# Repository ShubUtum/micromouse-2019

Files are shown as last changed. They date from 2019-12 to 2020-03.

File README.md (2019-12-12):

TODOs:

- [x] write a gitignore file
- [x] Timer Interrupt
- [x] PWM
- [x] UART TX, USB interface
- [x] Motor driver, H-Bridge interface
- [x] Motor Encoder 
- [x] PWM fix
- [x] ADC
- [ ] UART RX
- [ ] Schematic, routing
- [ ] PID controller
- [ ] moveing forward alignment & correction
- [ ] rotate left & right based on the POSCNT
- [ ] Map generation (maze discovery)
- [ ] finding shortest path to goal

- [ ] LED for measuring execution time
- [ ] UART, BT interface
- [ ] Visualization of UART data

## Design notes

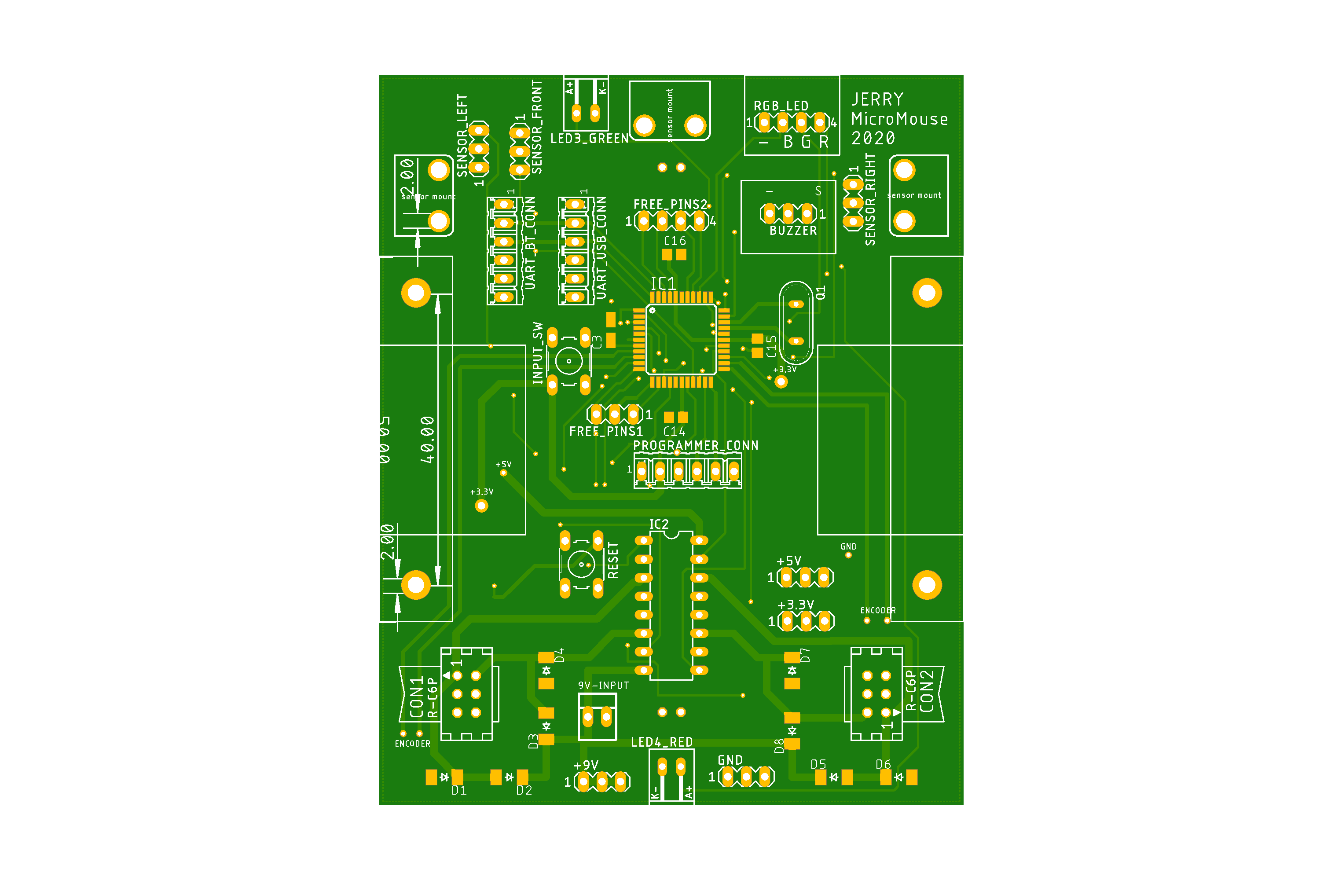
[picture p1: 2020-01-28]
Eagle/top.png

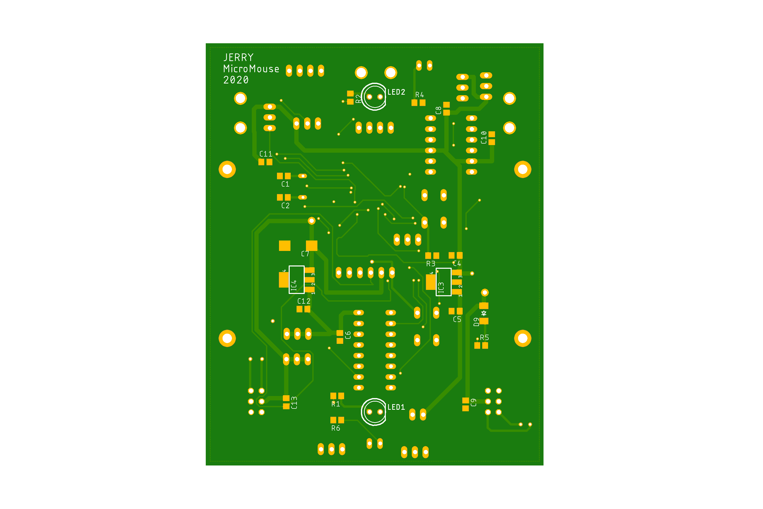
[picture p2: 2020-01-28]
Eagle/bottom.png

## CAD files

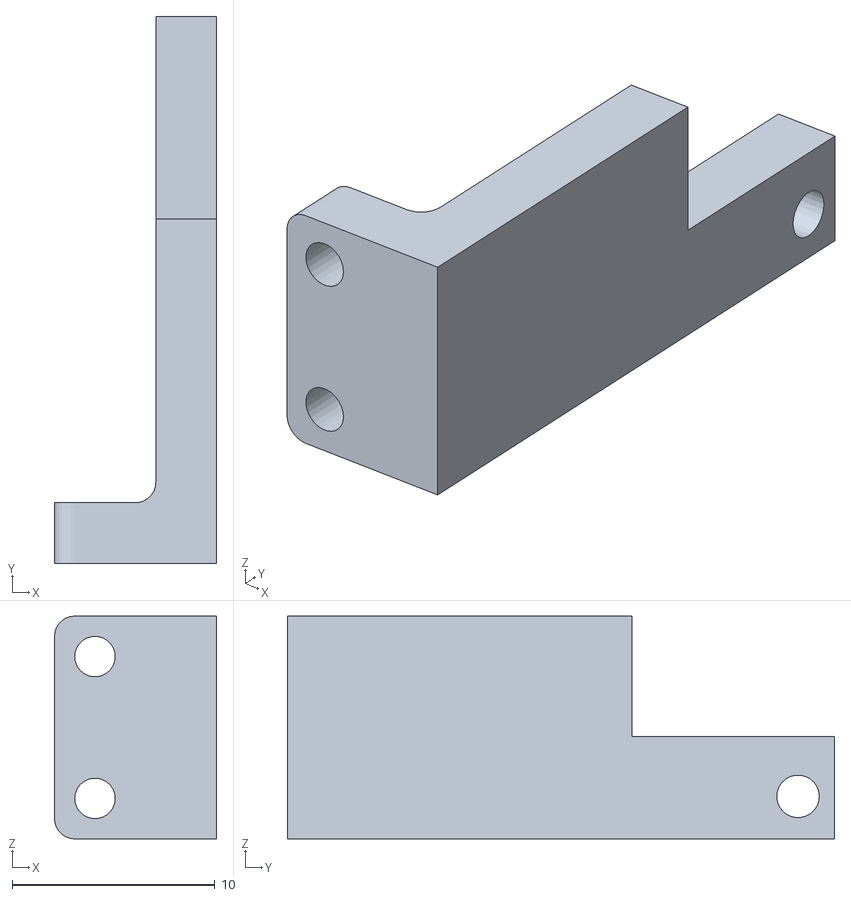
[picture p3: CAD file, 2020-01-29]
mount_models/sensormount.stl
8.00 x 27.0 x 11.0

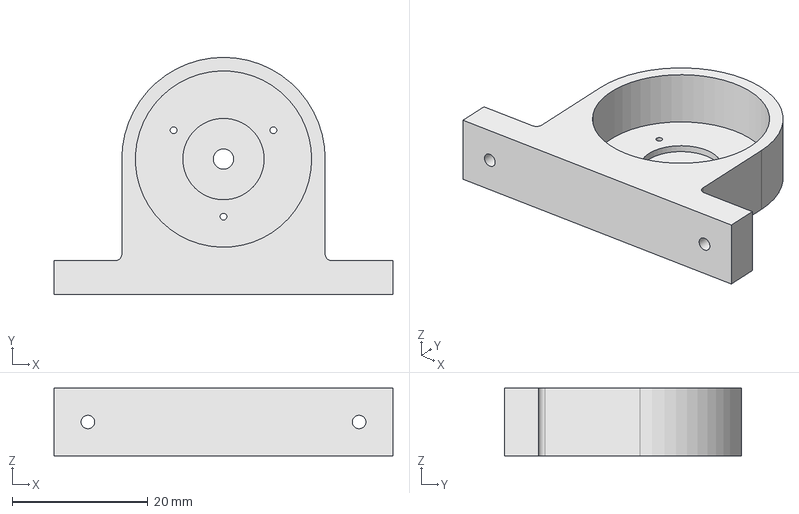
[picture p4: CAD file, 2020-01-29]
mount_models/skatch.FCStd
50.0 x 35.0 x 10.0 mm

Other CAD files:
mount_models/sensor.FCStd
mount_models/motormount.stl

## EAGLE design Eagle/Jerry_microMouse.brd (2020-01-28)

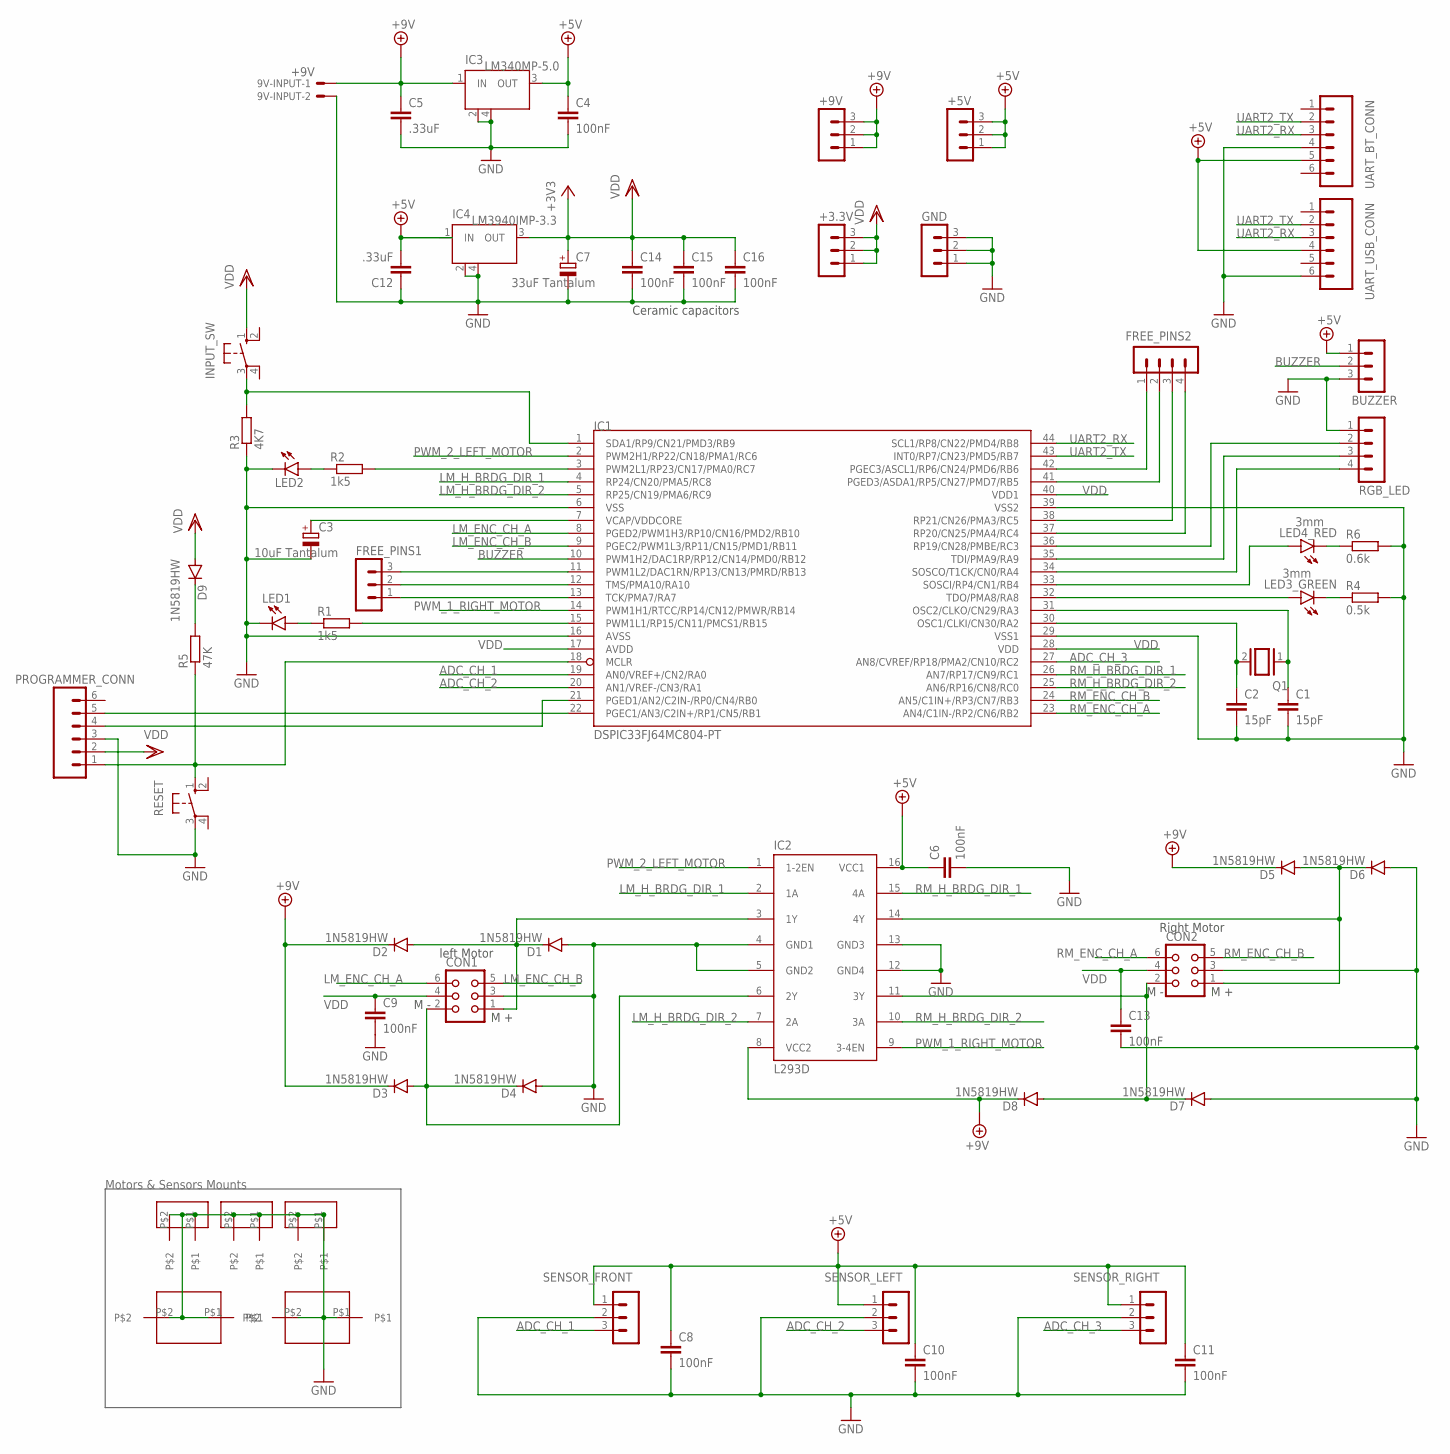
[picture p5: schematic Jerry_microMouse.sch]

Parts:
9V-INPUT: +9V; 22-23-2021
+3.3V, +5V, +9V: MA03-1
BUZZER: MA03-1
C1, C2: 15pF; C0805
C3: 10uF Tantalum; CT3216
C4, C6, C8, C9, C10, C11, C13, C14, C15, C16: 100nF; C0805
C5, C12: .33uF; C0805
C7: 33uF Tantalum; CT7343
CON1, CON2: CON06L
D1, D2, D3, D4, D5, D6, D7, D8, D9: 1N5819HW; SOD-123_MINI-SMA
FREE_PINS1: MA03-1
FREE_PINS2: MA04-1
GND: MA03-1
IC1: DSPIC33FJ64MC804-PT; TQFP44
IC2: L293D; DIL16
IC3: LM340MP-5.0; SOT223
IC4: LM3940IMP-3.3; SOT223
INPUT_SW: 10-XX; B3F-10XX
LED1, LED2: LED5MM
LED3_GREEN, LED4_RED: 3mm; Q62902-B155
PROGRAMMER_CONN: M06; 06P
Q1: XTAL/S; QS
R1, R2: 1k5; R0805
R3: 4K7; R0805
R4: 0.5k; R0805
R5: 47K; R0805
R6: 0.6k; R0805
RESET: 10-XX; B3F-10XX
RGB_LED: MA04-1
SENSOR_FRONT: MA03-1
SENSOR_LEFT: MA03-1
SENSOR_RIGHT: MA03-1
SENS_MNT_F: SENSOR_MOUNT_F; SENSOR_MOUNT
SENS_MNT_L: SENSOR_MOUNT_L; SENSOR_MOUNT
SENS_MNT_R: SENSOR_MOUNT_R; SENSOR_MOUNT
U$1, U$2: MOTOR_MOUNT
UART_BT_CONN: M06; 06P
UART_USB_CONN: M06; 06P

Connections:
+5V: +5V.1, +5V.2, +5V.3, BUZZER.1, C4.1, C6.1, C8.1, C10.1, C11.1, C12.2, IC2.16 (VCC1), IC3.3 (OUT), IC4.1 (IN), SENSOR_FRONT.1, SENSOR_LEFT.1, SENSOR_RIGHT.1, UART_BT_CONN.5, UART_USB_CONN.4
+9V: 9V-INPUT.1, +9V.1, +9V.2, +9V.3, C5.1, D2.C, D3.C, D5.C, D8.C, IC2.8 (VCC2), IC3.1 (IN)
ADC_CH_1: IC1.19 (AN0/VREF+/CN2/RA0), SENSOR_FRONT.3
ADC_CH_2: IC1.20 (AN1/VREF-/CN3/RA1), SENSOR_LEFT.3
ADC_CH_3: IC1.27 (AN8/CVREF/RP18/PMA2/CN10/RC2), SENSOR_RIGHT.3
BUZZER: BUZZER.2, IC1.10 (PWM1H2/DAC1RP/RP12/CN14/PMD0/RB12)
GND: 9V-INPUT.2, BUZZER.3, C1.2, C2.2, C3.-, C4.2, C5.2, C6.2, C7.-, C8.2, C9.2, C10.2, C11.2, C12.1, C13.2, C14.2, C15.2, C16.2, CON1.3, CON2.3, D1.A, D4.A, D6.A, D7.A, GND.1, GND.2, GND.3, IC1.6 (VSS), IC1.16 (AVSS), IC1.29 (VSS1), IC1.39 (VSS2), IC2.4 (GND1), IC2.5 (GND2), IC2.12 (GND4), IC2.13 (GND3), IC3.2 (GND), IC3.4 (GND), IC4.2 (GND), IC4.4 (GND), LED1.K (C), LED2.K (C), PROGRAMMER_CONN.3, R3.1, R4.2, R6.2, RESET.3, RGB_LED.1, SENSOR_FRONT.2, SENSOR_LEFT.2, SENSOR_RIGHT.2, SENS_MNT_F.P$1, SENS_MNT_F.P$2, SENS_MNT_L.P$1, SENS_MNT_L.P$2, SENS_MNT_R.P$1, SENS_MNT_R.P$2, U$1.P$1, U$1.P$2, U$2.P$1, U$2.P$2, UART_BT_CONN.4, UART_USB_CONN.6
LM_ENC_CH_A: CON1.6, IC1.8 (PGED2/PWM1H3/RP10/CN16/PMD2/RB10)
LM_ENC_CH_B: CON1.5, IC1.9 (PGEC2/PWM1L3/RP11/CN15/PMD1/RB11)
LM_H_BRDG_DIR_1: IC1.4 (RP24/CN20/PMA5/RC8), IC2.2 (1A)
LM_H_BRDG_DIR_2: IC1.5 (RP25/CN19/PMA6/RC9), IC2.7 (2A)
LM_M+: CON1.1, D1.C, D2.A, IC2.3 (1Y)
LM_M-: CON1.2, D3.A, D4.C, IC2.6 (2Y)
unnamed: IC1.3 (PWM2L1/RP23/CN17/PMA0/RC7), R2.2
unnamed: LED2.A, R2.1
unnamed: IC1.22 (PGEC1/AN3/C2IN+/RP1/CN5/RB1), PROGRAMMER_CONN.5
unnamed: IC1.1 (SDA1/RP9/CN21/PMD3/RB9), INPUT_SW.3, R3.2
unnamed: IC1.32 (TDO/PMA8/RA8), LED3_GREEN.A
unnamed: C2.1, IC1.30 (OSC1/CLKI/CN30/RA2), Q1.2
unnamed: C1.1, IC1.31 (OSC2/CLKO/CN29/RA3), Q1.1
unnamed: IC1.21 (PGED1/AN2/C2IN-/RP0/CN4/RB0), PROGRAMMER_CONN.4
unnamed: LED3_GREEN.K (C), R4.1
unnamed: IC1.15 (PWM1L1/RP15/CN11/PMCS1/RB15), R1.2
unnamed: IC1.33 (SOSCI/RP4/CN1/RB4), LED4_RED.A
unnamed: IC1.34 (SOSCO/T1CK/CN0/RA4), RGB_LED.4
unnamed: LED1.A, R1.1
unnamed: IC1.35 (TDI/PMA9/RA9), RGB_LED.3
unnamed: D9.C, R5.2
unnamed: IC1.36 (RP19/CN28/PMBE/RC3), RGB_LED.2
unnamed: FREE_PINS1.3, IC1.11 (PWM1L2/DAC1RN/RP13/CN13/PMRD/RB13)
unnamed: FREE_PINS2.1, IC1.42 (PGEC3/ASCL1/RP6/CN24/PMD6/RB6)
unnamed: FREE_PINS2.2, IC1.41 (PGED3/ASDA1/RP5/CN27/PMD7/RB5)
unnamed: FREE_PINS2.3, IC1.38 (RP21/CN26/PMA3/RC5)
unnamed: LED4_RED.K (C), R6.1
unnamed: FREE_PINS2.4, IC1.37 (RP20/CN25/PMA4/RC4)
unnamed: FREE_PINS1.2, IC1.12 (TMS/PMA10/RA10)
unnamed: FREE_PINS1.1, IC1.13 (TCK/PMA7/RA7)
PWM_1_RIGHT_MOTOR: IC1.14 (PWM1H1/RTCC/RP14/CN12/PMWR/RB14), IC2.9 (3-4EN)
PWM_2_LEFT_MOTOR: IC1.2 (PWM2H1/RP22/CN18/PMA1/RC6), IC2.1 (1-2EN)
RESET: IC1.18 (MCLR), PROGRAMMER_CONN.1, R5.1, RESET.1 (S)
RM_ENC_CH_A: CON2.6, IC1.23 (AN4/C1IN-/RP2/CN6/RB2)
RM_ENC_CH_B: CON2.5, IC1.24 (AN5/C1IN+/RP3/CN7/RB3)
RM_H_BRDG_DIR_1: IC1.26 (AN7/RP17/CN9/RC1), IC2.15 (4A)
RM_H_BRDG_DIR_2: IC1.25 (AN6/RP16/CN8/RC0), IC2.10 (3A)
RM_M+: CON2.1, D5.A, D6.C, IC2.14 (4Y)
RM_M-: CON2.2, D7.C, D8.A, IC2.11 (3Y)
UART2_RX: IC1.44 (SCL1/RP8/CN22/PMD4/RB8), UART_BT_CONN.3, UART_USB_CONN.3
UART2_TX: IC1.43 (INT0/RP7/CN23/PMD5/RB7), UART_BT_CONN.2, UART_USB_CONN.2
VCAP/VDDCORE: C3.+, IC1.7 (VCAP/VDDCORE)
VDD: +3.3V.1, +3.3V.2, +3.3V.3, C7.+, C9.1, C13.1, C14.1, C15.1, C16.1, CON1.4, CON2.4, D9.A, IC1.17 (AVDD), IC1.28 (VDD), IC1.40 (VDD1), IC4.3 (OUT), INPUT_SW.1 (S), PROGRAMMER_CONN.2

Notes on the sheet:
left Motor
Right Motor
M +
M -
Ceramic capacitors
Motors & Sensors Mounts

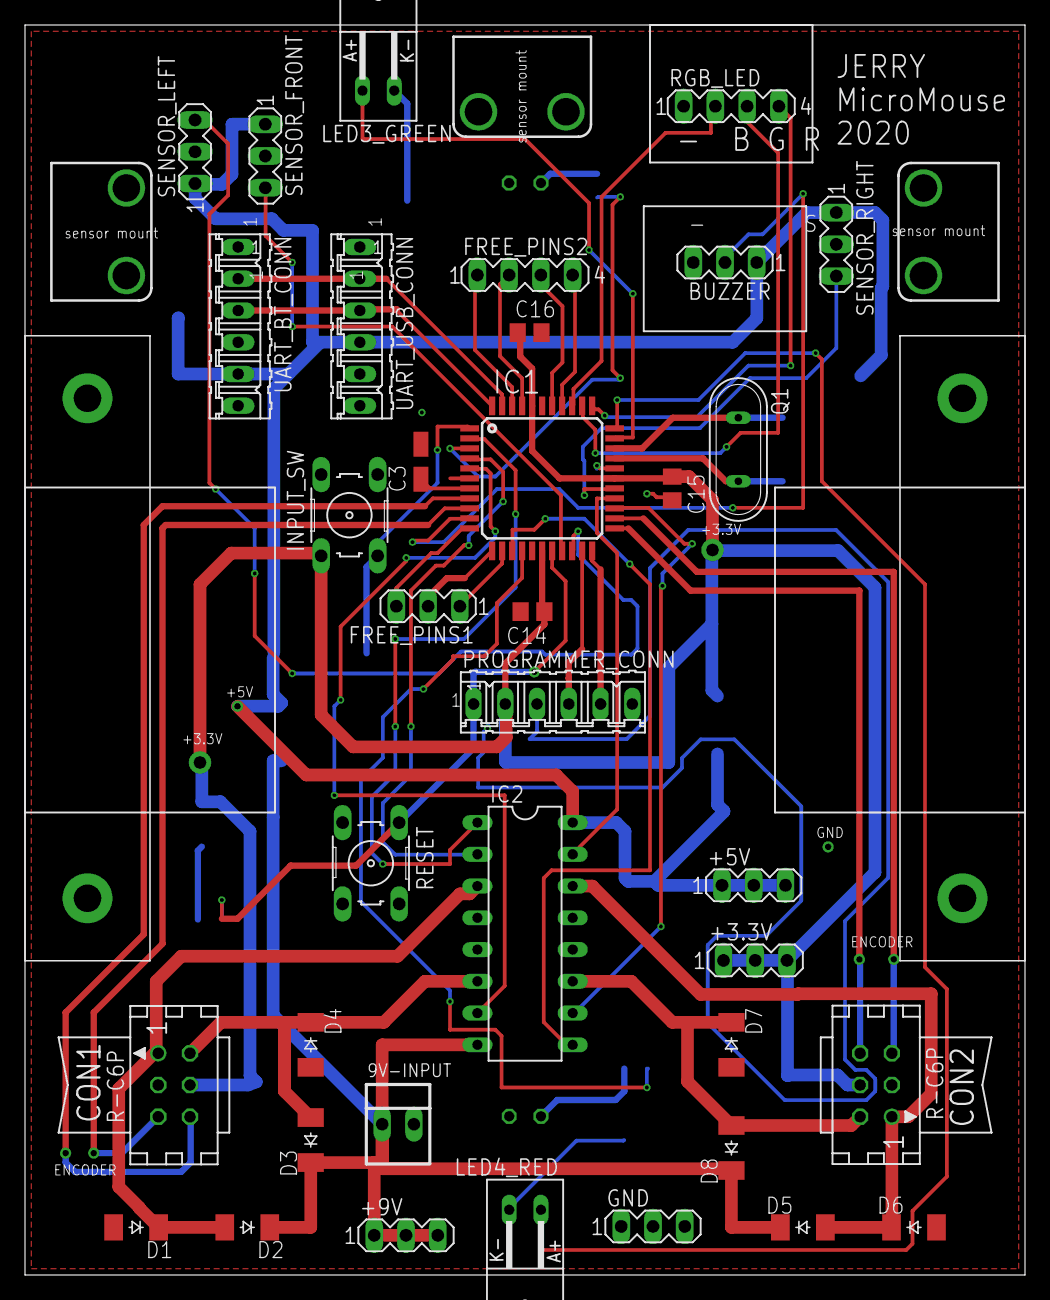
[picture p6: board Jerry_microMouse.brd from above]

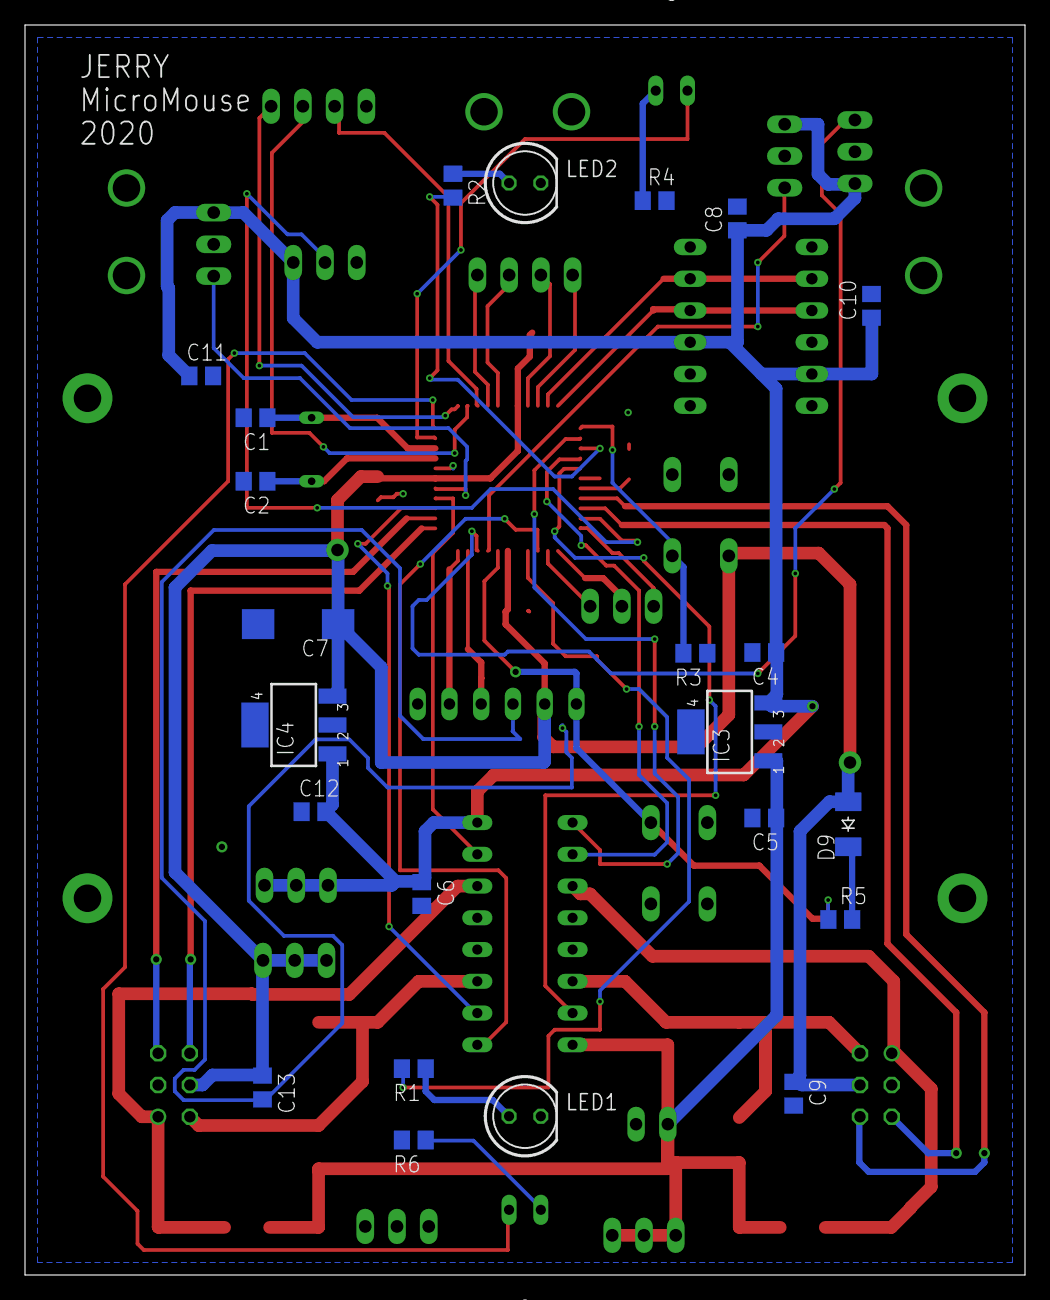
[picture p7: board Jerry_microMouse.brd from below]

Board: 2 copper layers, 80.0 x 100.0 mm, 64 parts (23 on the bottom side), 50 nets.

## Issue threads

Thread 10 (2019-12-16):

Visualization of UART data

SergeyMitchenko, 2019-12-16:
Visualize incoming UART data with a python script.
For example:
- Velocity of both motors
- Location in the maze
- Current state
- ...

(Feel free to add more)

SergeyMitchenko, 2020-01-29:
It's working right now. But it would be cool, if it would do it in real-time.

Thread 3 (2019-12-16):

Draw schematic and do the routing

SergeyMitchenko, 2019-12-16:
Draw a complete schematic and define routing of input and output pins.

Schematic has to be complete with all details.
Also, push table with all the pin mappings for quick overview over all pins.

SergeyMitchenko, 2019-12-16:
### Missing Components
- [ ] LEDs
- [ ] Decoupling Capacitors
- [ ] Power Supply (9V with two Voltage Regulators to 5V and 3V)
- [ ] Reset Button and Diode at the Programmer
- [ ] General Input Button
- [ ] Sensors
- [ ] All necessary resistors, capacitors and diods
- [ ] UART Module

### Additional ToDos
- [ ] download *.dru for Eagle from PCB Pool (Design Rules)
- [ ] add decoupling capacitors for sensors (100nF)
- [ ] add LEDs for debugging (e.g. through hole LEDs to balance the robot) (5mm low current LEDs or use a transistor SOT23)
- [ ] draw track board by hand

### Some Notes
- 10cm x 10cm PCB Board
- Resistors and capacitors of size 0805
- Supply motor with 9V and max duty cycle of 2/3 (regulate max DC according to battery voltage)
- use comments in schematic
- think about sizes and use screen layer to draw boxes
- Design connectors on circuit board so that it is easy to find correct alignment
- Use already available components (design system to use available components)

Diode:
https://de.rs-online.com/web/p/gleichrichterdioden-und-schottky-dioden/7082197/?sra=pstk

### Schematic from last semester
[micromouse1.pdf](https://github.com/ShubUtum/micromouse-2019/files/3967904/micromouse1.pdf)

SergeyMitchenko, 2020-03-07:
Done and PCB board is already ordered.

Closed 2020-03-07.

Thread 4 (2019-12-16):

Implement forward movement with alignment and correction

SergeyMitchenko, 2019-12-16:
Implement forward movement functionality, so that the robot is able to drive forward.
Sensors has to be used to measure the distance to the walls and for continuous correction of the alignment.
Cases:
- Left and right is a wall
- One wall is missing and the correction only depends on one distance
- Both walls are missing -> drive blindly forward until wall is found

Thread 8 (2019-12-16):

LED for measuring the execution time

SergeyMitchenko, 2019-12-16:
Just to measure the execution time of the program:
Toggle LED on at the start of the timer interrupt and toggle off at the end of the interrupt.

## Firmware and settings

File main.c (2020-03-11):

#include <xc.h> 
#include <stdio.h>
#include "timer.h"
#include "pwm.h"
#include "gpio.h"
#include "qei.h"
#include "uart.h"
#include "adc.h"
#include "dma.h"
#include "mouse.h"
#include "fsm.h"

#include "maze_solver.h"
// configuration bits, can be configured using GUI: window -> target memory views -> configuration bits 
/*
// FBS
#pragma config BWRP = WRPROTECT_OFF     // Boot Segment Write Protect (Boot Segment may be written)
#pragma config BSS = NO_FLASH           // Boot Segment Program Flash Code Protection (No Boot program Flash segment)

// FGS
#pragma config GWRP = OFF               // General Code Segment Write Protect (User program memory is not write-protected)
#pragma config GSS = OFF                // General Segment Code Protection (User program memory is not code-protected)

// FOSCSEL
#pragma config FNOSC = PRIPLL           // Oscillator Mode (Primary Oscillator (XT, HS, EC) w/ PLL)
#pragma config IESO = ON                // Internal External Switch Over Mode (Start-up device with FRC, then automatically switch to user-selected oscillator source when ready)

// FOSC
#pragma config POSCMD = HS              // Primary Oscillator Source (HS Oscillator Mode)
#pragma config OSCIOFNC = OFF           // OSC2 Pin Function (OSC2 pin has clock out function)
#pragma config IOL1WAY = OFF           // Peripheral Pin Select Configuration (Allow Multiple Re-configurations)
#pragma config FCKSM = CSDCMD           // Clock Switching and Monitor (Both Clock Switching and Fail-Safe Clock Monitor are disabled)

// FWDT
#pragma config WDTPOST = PS1            // Watchdog Timer Postscaler (1:1)
#pragma config WDTPRE = PR128           // WDT Prescaler (1:128)
#pragma config WINDIS = OFF             // Watchdog Timer Window (Watchdog Timer in Non-Window mode)
#pragma config FWDTEN = OFF             // Watchdog Timer Enable (Watchdog timer enabled/disabled by user software)

// FPOR
#pragma config FPWRT = PWR1             // POR Timer Value (Disabled)
#pragma config ALTI2C = OFF             // Alternate I2C  pins off
#pragma config LPOL = ON                // Motor Control PWM Low Side Polarity bit (PWM module low side output pins have active-high output polarity)
#pragma config HPOL = ON                // Motor Control PWM High Side Polarity bit (PWM module high side output pins have active-high output polarity)
#pragma config PWMPIN = ON              // Motor Control PWM Module Pin Mode bit (PWM module pins controlled by PORT register at device Reset)

// FICD
#pragma config ICS = PGD1               // Comm Channel Select (Communicate on PGC1/EMUC1 and PGD1/EMUD1)
#pragma config JTAGEN = OFF             // JTAG Port Enable (JTAG is Disabled)
*/

// DSPIC33FJ128MC804 Configuration Bit Settings
// FBS
#pragma config BWRP = WRPROTECT_OFF     // Boot Segment Write Protect (Boot Segment may be written)
#pragma config BSS = NO_FLASH           // Boot Segment Program Flash Code Protection (No Boot program Flash segment)
#pragma config RBS = NO_RAM             // Boot Segment RAM Protection (No Boot RAM)

// FSS
#pragma config SWRP = WRPROTECT_OFF     // Secure Segment Program Write Protect (Secure segment may be written)
#pragma config SSS = NO_FLASH           // Secure Segment Program Flash Code Protection (No Secure Segment)
#pragma config RSS = NO_RAM             // Secure Segment Data RAM Protection (No Secure RAM)

// FGS
#pragma config GWRP = OFF               // General Code Segment Write Protect (User program memory is not write-protected)
#pragma config GSS = OFF                // General Segment Code Protection (User program memory is not code-protected)

// FOSCSEL
#pragma config FNOSC = LPRCDIVN         // Oscillator Mode (Internal Fast RC (FRC) with divide by N)
//#pragma config FNOSC = PRIPLL           // Oscillator Mode (Primary Oscillator (XT, HS, EC) w/ PLL)
#pragma config IESO = ON                // Internal External Switch Over Mode (Start-up device with FRC, then automatically switch to user-selected oscillator source when ready)

// FOSC
#pragma config POSCMD = HS              // Primary Oscillator Source (HS Oscillator Mode)
#pragma config OSCIOFNC = OFF           // OSC2 Pin Function (OSC2 pin has clock out function)
#pragma config IOL1WAY = OFF            // Peripheral Pin Select Configuration (Allow Multiple Re-configurations)
#pragma config FCKSM = CSECME           // Clock Switching and Monitor (Both Clock Switching and Fail-Safe Clock Monitor are enabled)
//#pragma config FCKSM = CSDCMD           // Clock Switching and Monitor (Both Clock Switching and Fail-Safe Clock Monitor are disabled)

// FWDT
//#pragma config WDTPOST = PS32768        // Watchdog Timer Postscaler (1:32,768)
#pragma config WDTPOST = PS1            // Watchdog Timer Postscaler (1:1)
#pragma config WDTPRE = PR128           // WDT Prescaler (1:128)
#pragma config WINDIS = OFF             // Watchdog Timer Window (Watchdog Timer in Non-Window mode)
#pragma config FWDTEN = OFF             // Watchdog Timer Enable (Watchdog timer enabled/disabled by user software)

// FPOR
#pragma config FPWRT = PWR128           // POR Timer Value (128ms)
#pragma config ALTI2C = OFF             // Alternate I2C  pins (I2C mapped to SDA1/SCL1 pins)
#pragma config LPOL = ON                // Motor Control PWM Low Side Polarity bit (PWM module low side output pins have active-high output polarity)
#pragma config HPOL = ON                // Motor Control PWM High Side Polarity bit (PWM module high side output pins have active-high output polarity)
#pragma config PWMPIN = ON              // Motor Control PWM Module Pin Mode bit (PWM module pins controlled by PORT register at device Reset)

// FICD
#pragma config ICS = PGD1               // Comm Channel Select (Communicate on PGC1/EMUC1 and PGD1/EMUD1)
#pragma config JTAGEN = OFF             // JTAG Port Enable (JTAG is Disabled)

#define IN_SIMULATION_MODE  0

int main(void) {
    
    /*** oscillator setup --------------------------------------------------
    Here we are using PPL for 16MHz to generate 80MHz clock.
    FCY = 0.5 * (16MHz*20/(2*2)) = 40 MIPS
    ---------------------------------------------------------------------***/
    PLLFBDbits.PLLDIV  = 18; //set PPL to M=20 (18+2)
    CLKDIVbits.PLLPRE  = 0; //N1 = input/2
    CLKDIVbits.PLLPOST = 0; //N2 = output/2
    CLKDIVbits.FRCDIV  = 0;
    // Disable Watch Dog Timer
    RCONbits.SWDTEN=0;
    // Clock switch to incorporate PLL
    __builtin_write_OSCCONH( 0x03 );            // Initiate Clock Switch to Primary
    // Oscillator with PLL (NOSC=0b011)
    __builtin_write_OSCCONL( OSCCON || 0x01 );  // Start clock switching
    
    while( OSCCONbits.COSC != 0b011 );
    // In reality, give some time to the PLL to lock
    if (IN_SIMULATION_MODE != 1)
    {
       while (OSCCONbits.LOCK != 1); //Wait for PPL to lock
    }

    initIO();
    
    GREEN_LED = 1;
    RED_LED = 1;
    RGB(RED|GREEN|BLUE);
    BACK_LED = 1;
    FRONT_LED = 1;

    configUART2(57.6, 40);
    //configUART2(38.4, 40);   // BT baudrate 38400
    
    timer1_setup( 10 );        // 10 ms timer 

    LOG( "\n\r\n\r\n\r.....   START MICRO-MOUSE   ..... \n\r" );

    setupADC1();
    initDmaChannel4();

    mouse_init();
    fsm_init();

    startADC1();
    timer1_start();
    
    while(1);

    return 0;
}

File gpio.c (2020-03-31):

#include "gpio.h"
#include "uart.h"


uint16_t error_flag = 0;

#if IN_BREAD_BOARD_MODE
void initIO() {
    int i;
    /***********************************************************************
     *  PIN#     name        I/O   mappable?  function                                          Bread board change?
     ***********************************************************************
     *   17     PWM2H1(RB8)   op     N        PWM2 Left Motor Speed    (RED LED)
     *   25     PWM1H1(RB14)  op     N        PWM1 Right Motor Speed
     * 
     *   2       AN0(RA0)     ip     N        ADC ch 1
     *   3       AN1(RA1)     ip     N        ADC ch 2
     *   4       AN2(RB0)     ip     N        ADC ch 3
     * 
     *   23      RB12         op     Y        UART2 TX
     *   24      RB13         ip     Y        UART2 RX
     * 
     *   6       RB2          ip     Y        QEI1 A - Left Motor encoder ch A
     *   7       RB3          ip     Y        QEI1 B - Left Motor encoder ch B
     *   21      RB10         ip     Y        QEI2 A - Right Motor encoder ch A
     *   22      RB11         ip     Y        QEI2 B - Right Motor encoder ch B
     * 
     *   11      RB4          op     Y        GP - Left Motor H bridge dir control 1                  Yes
     *   14      RB5          op     Y        GP - Left Motor H bridge dir control 2                  Yes
     *   15      RB6          op     Y        GP - Right Motor H bridge dir control 1
     *   16      RB7          op     Y        GP - Right Motor H bridge dir control 2
     * 
     *   26      RB15         op     Y        GP - output(GREEN LED)                                  Yes
     *   12      RA4          ip     Y        Switch                                                  Yes
     * 
     *   5       AN3(RB1)                     FREE
     *   18      RB9                          FREE
     ***********************************************************************/
    // set up analog pins
    AD1CON1bits.ADON = 0; // disable ADC1 module
    AD1PCFGL=0xFFFF; //all pins are digital
   
    // set digital port direction
    // inputs
    //all pins are inputs by default
    TRISAbits.TRISA4  =1; //Switch input
    //TRISBbits.TRISB13 =1; //UART2 RX
    //TRISBbits.TRISB2  =1; //QEI1 A
    //TRISBbits.TRISB3  =1; //QEI1 B

    //outputs
    TRISBbits.TRISB8  =0; //PWM2H1 & RED LED output
    TRISBbits.TRISB15 =0; //GREEN LED output
    TRISBbits.TRISB6  =0; //RED LED
    TRISBbits.TRISB8  =0; //PWM_RED LED
    TRISBbits.TRISB4  =0; //H bridge dir control 1
    TRISBbits.TRISB5  =0; //H bridge dir control 2
    //TRISBbits.TRISB12 =0; //UART2 TX
    

    // set up remappable pins
    __builtin_write_OSCCONL(OSCCON & 0xbf); // clear bit 6 (unlock, they are usually write protected)
    // inputs
     // input pin mapping example below:, here you choose the register with the device and assign an remappable pin
    RPINR14bits.QEA1R = 2; // QEI1 A to pin RB2
    RPINR14bits.QEB1R = 3; // QEI1 B to pin RB3
    RPINR16bits.QEA2R = 10; //QEI2 A to pin RB10
    RPINR16bits.QEB2R = 11; //QEI2 B to pin RB11
    
    RPINR19bits.U2RXR = 13; // input from uart to pin RB13
    //RPINR18bits.U1RXR = 1 ; //U1RX register is pin RB1 / RP1
    
    // outputs
    //output pin mapping example below, here you choose the pin register and then map it to a device 
    //RPOR6bits.RP12R = 0b00111; // pin RB12 to SPI1 miso (the cod 0b00111 idetifies SPI miso, table in datasheet)  
    //RPOR1bits.RP2R = 0b00011; // pin RP2 is connected to UART1 TX, for coding see table 11-2 in datasheet
    //end of set up of remappable pins
    
    RPOR6bits.RP12R = 0b00101;  // Map RB12 to U2TX UART2 Transmit
    
    RPOR4bits.RP8R  = 0; //default pin output for PWM2H1 (RED LED)
    RPOR7bits.RP14R = 0; //default pin output for PWM1H1 
    
    RPOR2bits.RP4R  = 0; //default pin output for H bridge dir control 
    RPOR2bits.RP5R  = 0; //default pin output for H bridge dir control 
    RPOR3bits.RP6R  = 0; //default pin output for H bridge dir control 
    RPOR3bits.RP7R  = 0; //default pin output for H bridge dir control 
    
    RPOR7bits.RP15R = 0; //default pin output for GREEN LED //0 is default
    
    __builtin_write_OSCCONL(OSCCON | 0x40); // Lock PPS registers (lock again!)


    for (i = 0; i < 30000; i++); // short delay
}
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

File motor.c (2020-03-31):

#include <xc.h>
#include <stdio.h>
#include "gpio.h"
#include "qei.h"
#include "uart.h"
#include "pwm.h"
#include "pid.h"
#include "motor.h"


#define GET_LM_SPEED       qei1_get_poscnt()
#define GET_RM_SPEED       qei2_get_poscnt()

#define MOTOR_MAX_PWM_DC    (100*6/9) // 100% * 6v/9v

int         LM_curr_speed;  // LM moved POSCNT/10ms
int         RM_curr_speed;  // RM moved POSCNT/10ms
pid_params  LM_pid;
pid_params  RM_pid;
/************************************************************************
 ************************************************************************/
void init_left_motor( void )
{   
   // base_resolution = 16; gearing_ratio = 33; edge_gain = 4;
   init_QEI_1(16, 33, 4, 0);
   init_pwm2( 1, 0 );   // 1KHz PWM (1ms period)

   init_pid( &LM_pid,
             0.7,                                   // kp
             0.05,                                  // ki
             -MOTOR_MAX_SPEED, MOTOR_MAX_SPEED,     // Motor speed range (PID ip range)
             -MOTOR_MAX_PWM_DC, MOTOR_MAX_PWM_DC    // PWM DC range (PID op range)
           );

   LM_curr_speed = GET_LM_SPEED;
   //LOG("Left Motor ready\n\r");
}

/************************************************************************
 ************************************************************************/
void init_right_motor( void )
{
   // base_resolution = 16; gearing_ratio = 33; edge_gain = 4;
   init_QEI_2(16, 33, 4, 0);
   init_pwm1( 1, 0 );   // 1KHz PWM (1ms period)

   init_pid( &RM_pid,
             0.7,                                   // kp
             0.05,                                  // ki
             -MOTOR_MAX_SPEED, MOTOR_MAX_SPEED,     // Motor speed range (PID ip range)
             -MOTOR_MAX_PWM_DC, MOTOR_MAX_PWM_DC    // PWM DC range (PID op range)
           );

   RM_curr_speed = GET_RM_SPEED;
   //LOG("Right Motor ready\n\r");
}

void calc_motors_speed( void ) {

   LM_curr_speed = GET_LM_SPEED;
   RM_curr_speed = GET_RM_SPEED;
}

void get_motors_moved_dist( int* LM_dist, int* RM_dist ) {

   *LM_dist = LM_curr_speed;
   *RM_dist = RM_curr_speed;
}

void left_motor_perform( int desired_speed ){
    int pwm_dc;
    
    //if( desired_speed > MOTOR_MAX_SPEED ) desired_speed = MOTOR_MAX_SPEED;
    
    pwm_dc = pid_control( &LM_pid, LM_curr_speed, desired_speed );

    //H bridge control
    if( desired_speed == 0 || pwm_dc == 0 ) {         // brake
        LM_DIR1 = 0;
        LM_DIR2 = 0;
        pwm2_change_dc( 0 );
    }else if( pwm_dc > 0 ) {    // Forward
        LM_DIR1 = 1;
        LM_DIR2 = 0;
        pwm2_change_dc( pwm_dc );
    }
    else {                      // Backward
        LM_DIR1 = 0;
        LM_DIR2 = 1;
        //pwm_dc = -1*pwm_dc;
        //LOG( "pwm2 DC = %d\n\r", -pwm_dc );
        pwm2_change_dc( (-pwm_dc) );
    }
}

void right_motor_perform( int desired_speed ){    
    int pwm_dc;
    
    //if( desired_speed > MOTOR_MAX_SPEED ) desired_speed = MOTOR_MAX_SPEED;
    
    pwm_dc = pid_control( &RM_pid, RM_curr_speed, desired_speed );

    //H bridge control
    if( desired_speed == 0 || pwm_dc == 0 ) {         // brake
        RM_DIR1 = 0;
        RM_DIR2 = 0;
        pwm1_change_dc( 0 );
    }else if( pwm_dc > 0 ) { // Forward
        RM_DIR1 = 1;
        RM_DIR2 = 0;
        pwm1_change_dc( pwm_dc );
    }
    else {                  // Backward
        RM_DIR1 = 0;
        RM_DIR2 = 1;
        pwm1_change_dc( -pwm_dc );
    }
}

// calc the Motor max speed in POSCNT/10ms unit
void motor_calc_max_speed( void ) {
    static uint16_t time_idx = 0;

    if( time_idx == 0 ) {    // first_call
       init_left_motor();
       init_right_motor();
       // drive motor with high speed
       LM_DIR1 = 1; LM_DIR2 = 0; pwm2_change_dc( MOTOR_MAX_PWM_DC );
       RM_DIR1 = 1; RM_DIR2 = 0; pwm1_change_dc( MOTOR_MAX_PWM_DC );
    }
    
    if( time_idx < 200 ) {  // 200 = 2 Seconds
        LOG( "%d: LM_v = %d\t\t RM_v = %d\n\r", time_idx, LM_curr_speed, RM_curr_speed );
        time_idx++;
    }
}
 
void test_motor_PI_control( uint16_t desired_speed ) {
    uint16_t motor_pwm_dc = 0;
    static uint16_t time_idx = 0;
    int16_t current_speed;

    if( time_idx == 0 ) {    // first_call
       init_left_motor();
       init_right_motor();
    }
    
    if( time_idx < 200 ) {  // 200 = 2 Seconds
        current_speed = LM_curr_speed;
        motor_pwm_dc = pid_control( &LM_pid, current_speed, desired_speed);
        LM_DIR1 = 1; LM_DIR2 = 0; pwm2_change_dc( motor_pwm_dc );
        LOG( "%d: LM = %d, %d\t-\t", time_idx, current_speed, motor_pwm_dc );
        
        current_speed = RM_curr_speed;
        motor_pwm_dc = pid_control( &RM_pid, current_speed, desired_speed);
        RM_DIR1 = 1; RM_DIR2 = 0; pwm1_change_dc( motor_pwm_dc );
        LOG( "RM = %d, %d\n\r", current_speed, motor_pwm_dc );
       
       time_idx++;
    }
}

void test_motor( void ){
    static int speed = MOTOR_MAX_SPEED;
    LOG( "LM_V=%d \t\t RM_V=%d\n\r", LM_curr_speed, RM_curr_speed );

    left_motor_perform( speed );
    right_motor_perform( (-1*speed) );

    // increase DC 
    //speed = (speed+10) % MOTOR_MAX_SPEED;
}

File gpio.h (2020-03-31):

/* 
 * File:   gpio.h
 * Author: a2-lenz
 *
 * Created on April 5, 2019, 11:31 AM
 */

#ifndef GPIO_H
#define	GPIO_H

#include "xc.h"
#include <stdio.h>

#define IN_BREAD_BOARD_MODE  0


#if IN_BREAD_BOARD_MODE

#define PWM_RED_LED LATBbits.LATB8
#define RED_LED     LATBbits.LATB6
#define GREEN_LED   LATBbits.LATB15
#define SW1         PORTAbits.RA4

#define CTRLH_INPUT1 LATBbits.LATB4
#define CTRLH_INPUT2 LATBbits.LATB5
#else

#define BACK_LED     LATBbits.LATB4
#define FRONT_LED    LATAbits.LATA8

#define RED_LED     LATBbits.LATB15
#define GREEN_LED   LATCbits.LATC7

#define SW1         PORTBbits.RB9

#define LM_DIR1 LATCbits.LATC8
#define LM_DIR2 LATCbits.LATC9
#define RM_DIR1 LATCbits.LATC0
#define RM_DIR2 LATCbits.LATC1

typedef enum {
   ALL_OFF  = 0x00,
   RED      = 0x01,  // BIT 0
   GREEN    = 0x02,  // BIT 1
   BLUE     = 0x04   // BIT 2
} rgb_color;

#endif    

void initIO();

void error();

void RGB( uint16_t color);

#endif	/* GPIO_H */

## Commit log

2019-11-17 add PWM driver, and test it in main function
2019-11-26 [+] added motor perform function to control motor with h-bridge [untested]
2019-11-26 QEI (Encoder) module implemented
2019-11-27 [+] added uart function [UNTESTED]
2019-11-27 [~] update uart [TESTED]
2019-11-27 [~] moved some code into uart.h
2019-12-02 fix PWM, adding ADC & DMA files, code organization
    [adc.c, dma.c, gpio.c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]
2019-12-04 [~] fixed control input direction bug
    [pwm.c, timer.c]
2019-12-04 [~] fixed poscnt bug, fixed uart sendString function, fixed h bridge pwm problem
    [pwm.c, qei.c, timer.c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]
2019-12-09 add PWM 1
2019-12-10 [+] added ADC with implemented DMA handler [UNTESTED]
2019-12-10 [~] adjusted data type conversion in DMA interrupt handler
2019-12-11 [+] added ADC + DMA [TESTED]
2019-12-12 adding the initial schematic diagram, update the task list in README
    [microMouse_schematic.sch]
2019-12-16 UART receive functionality
2019-12-18 [incomplete] adding motor speed PI controller. organize Timer interrupt function
2019-12-18 [+] add schematic for H-bridge
2020-01-04 [+] added voltage regulator, reset switch, LEDs
    [microMouse_schematic.sch]
2020-01-04 [~] clean up unused wire and component
    [microMouse_schematic.sch]
2020-01-07 finish PID [untested] , finish schematic
    [microMouse_schematic.sch]
2020-01-08 add UART socket to schematic, adjust Voltage reg
    [microMouse_schematic.sch]
2020-01-10 recover PID code, add PID test code
2020-01-13 update schematic, finish placing components on board
    [microMouse_schematic.brd, microMouse_schematic.sch]
2020-01-15 PCB signals routing
    [microMouse_schematic.brd, microMouse_schematic.sch]
2020-01-19 add motor & sensor mounts, add GND planes
    [microMouse_schematic.brd, microMouse_schematic.sch]
2020-01-28 update PCB, manually routing
    [Jerry_microMouse.brd, Jerry_microMouse.sch]
2020-01-29 moved motor mount from master to drivers branch
    [motormount.stl, skatch.FCStd]
2020-01-29 motor mount and sensor mount
    closes #13 and closes #14
    [motormount.stl, sensor.FCStd, sensormount.stl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]
2020-03-01 - add pushButton.c, - update gpio with pin mappings for Jerry board, - add simple FSM (idle, search, navigate states) in fsm.c, - add RGB function to gpio.c, - add mouse move FW, BW, rotate left, rig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
2020-03-05 Auto stash before merge of "drivers" and "origin/drivers"
2020-03-11 switch clk source from internal to external HS crystal w PLL, all modules are working
